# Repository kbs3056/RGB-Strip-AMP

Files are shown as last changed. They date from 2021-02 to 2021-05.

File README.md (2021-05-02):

# RGB-Strip-AMP

12V RGB LED strip amplifier is used to reduce the voltage drop in long LED strips.

### Output
3x1.5A, 2.5-5m 5050 LED.

Amplifier needs an external 12V and GND supply lines.
All LED strips connected in one circuit should be powered by the same power supply. (Input 12V and Output 12V rails are connected.)

See wiring diagram. https://github.com/kbs3056/RGB-Strip-AMP/blob/main/wiring_diagram.pdf

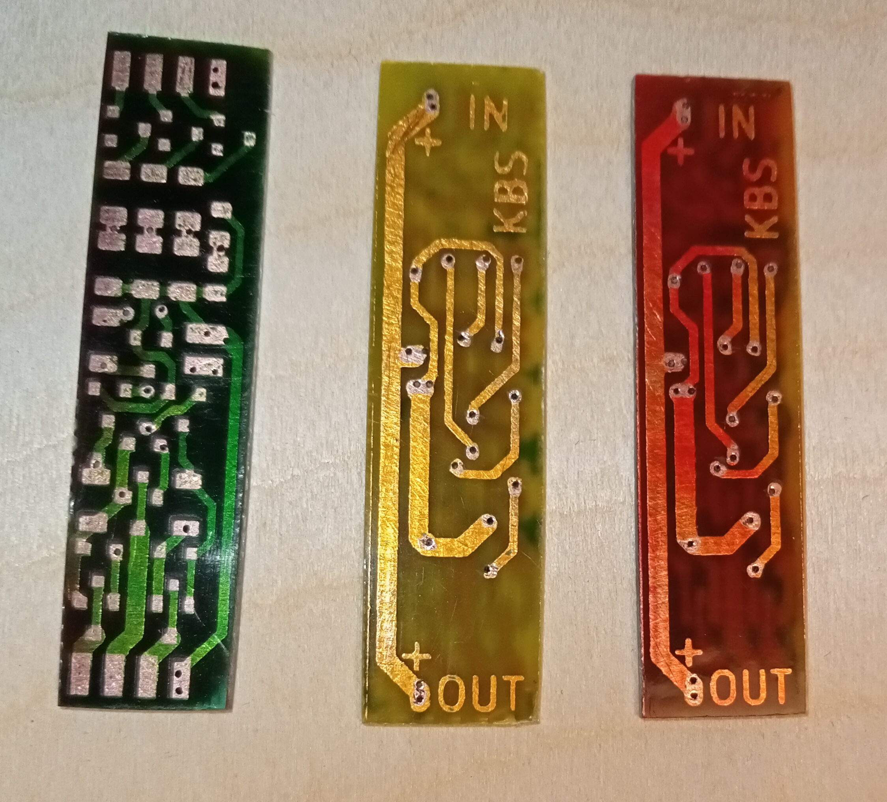
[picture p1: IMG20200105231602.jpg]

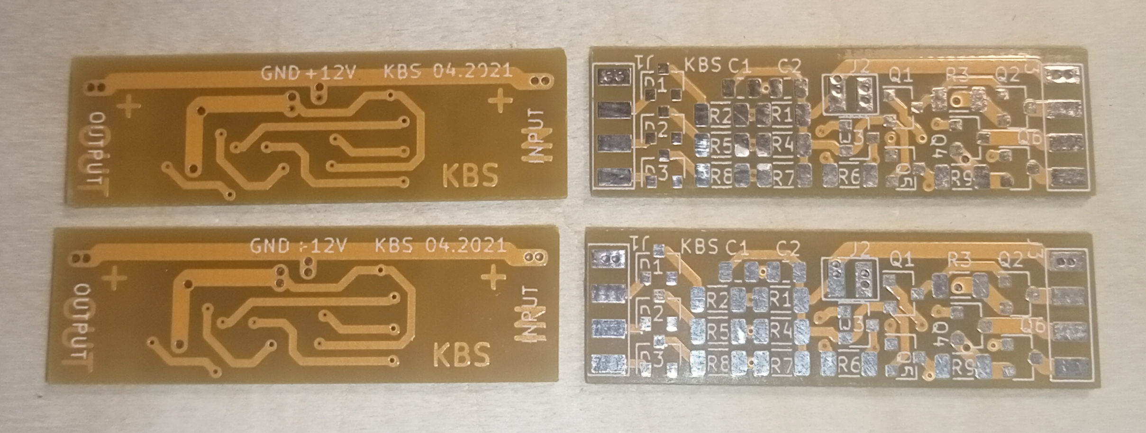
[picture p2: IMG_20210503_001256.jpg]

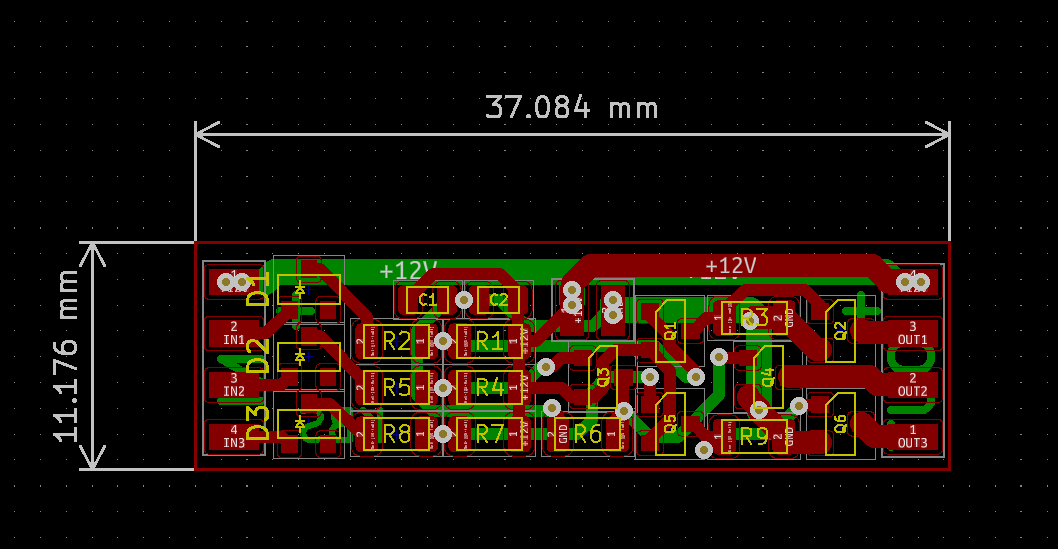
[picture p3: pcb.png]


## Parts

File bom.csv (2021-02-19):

Reference | Quantity | Value | Footprint | Datasheet
C1 | 1 | 1u | Capacitor_SMD:C_0805_2012Metric | ~
C2 | 1 | 100n | Capacitor_SMD:C_0805_2012Metric | ~
D1 D2 D3 | 3 | 3V9 | Diode_SMD:D_SOT-23_ANK | ~
Q1 Q3 Q5 | 3 | MMBT3906 | Package_TO_SOT_SMD:SOT-23 | https://www.onsemi.com/pub/Collateral/2N3906-D.PDF
Q2 Q4 Q6 | 3 | AO3400A | Package_TO_SOT_SMD:SOT-23 | http://www.aosmd.com/pdfs/datasheet/AO3400A.pdf
R1 R2 R3 R4 R5 R6 R7 R8 R9 | 9 | 4k7 | Resistor_SMD:R_1206_3216Metric | ~

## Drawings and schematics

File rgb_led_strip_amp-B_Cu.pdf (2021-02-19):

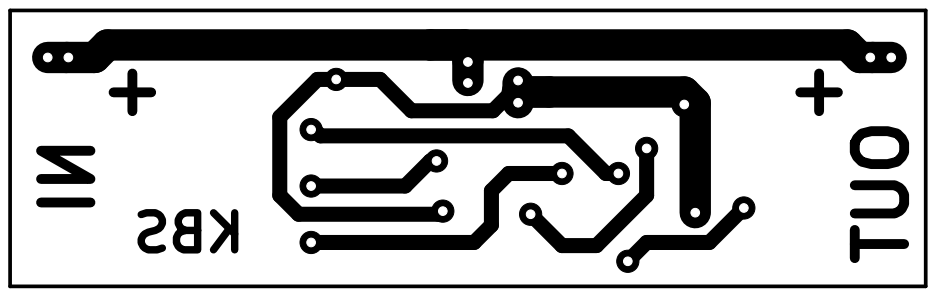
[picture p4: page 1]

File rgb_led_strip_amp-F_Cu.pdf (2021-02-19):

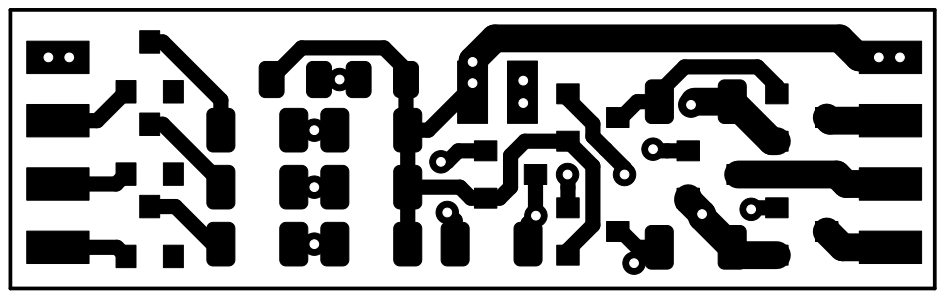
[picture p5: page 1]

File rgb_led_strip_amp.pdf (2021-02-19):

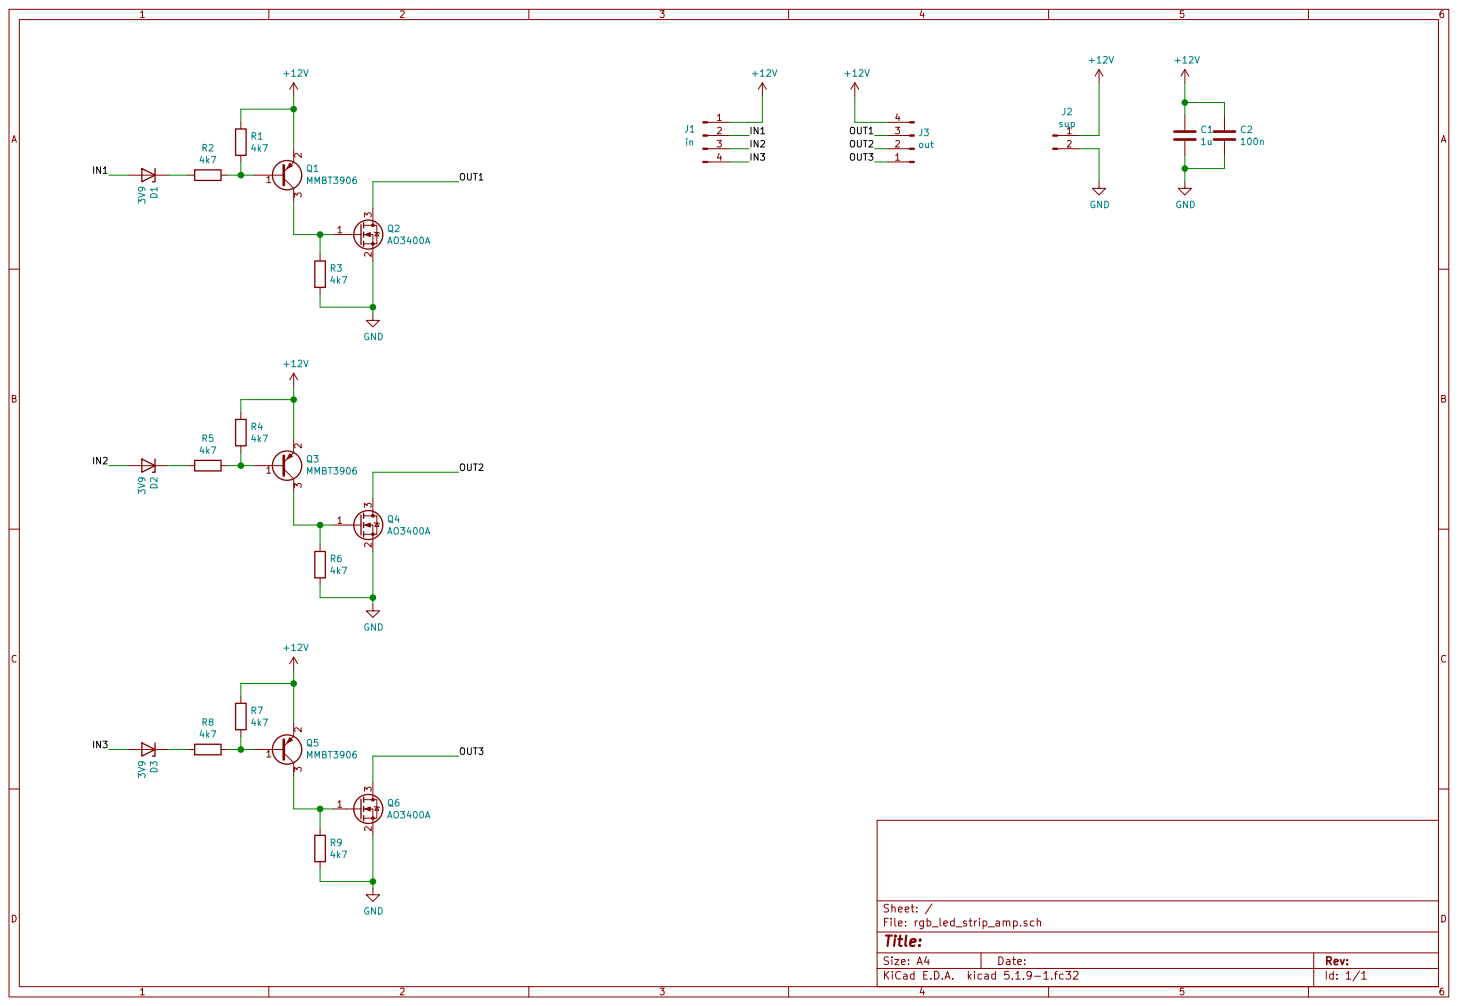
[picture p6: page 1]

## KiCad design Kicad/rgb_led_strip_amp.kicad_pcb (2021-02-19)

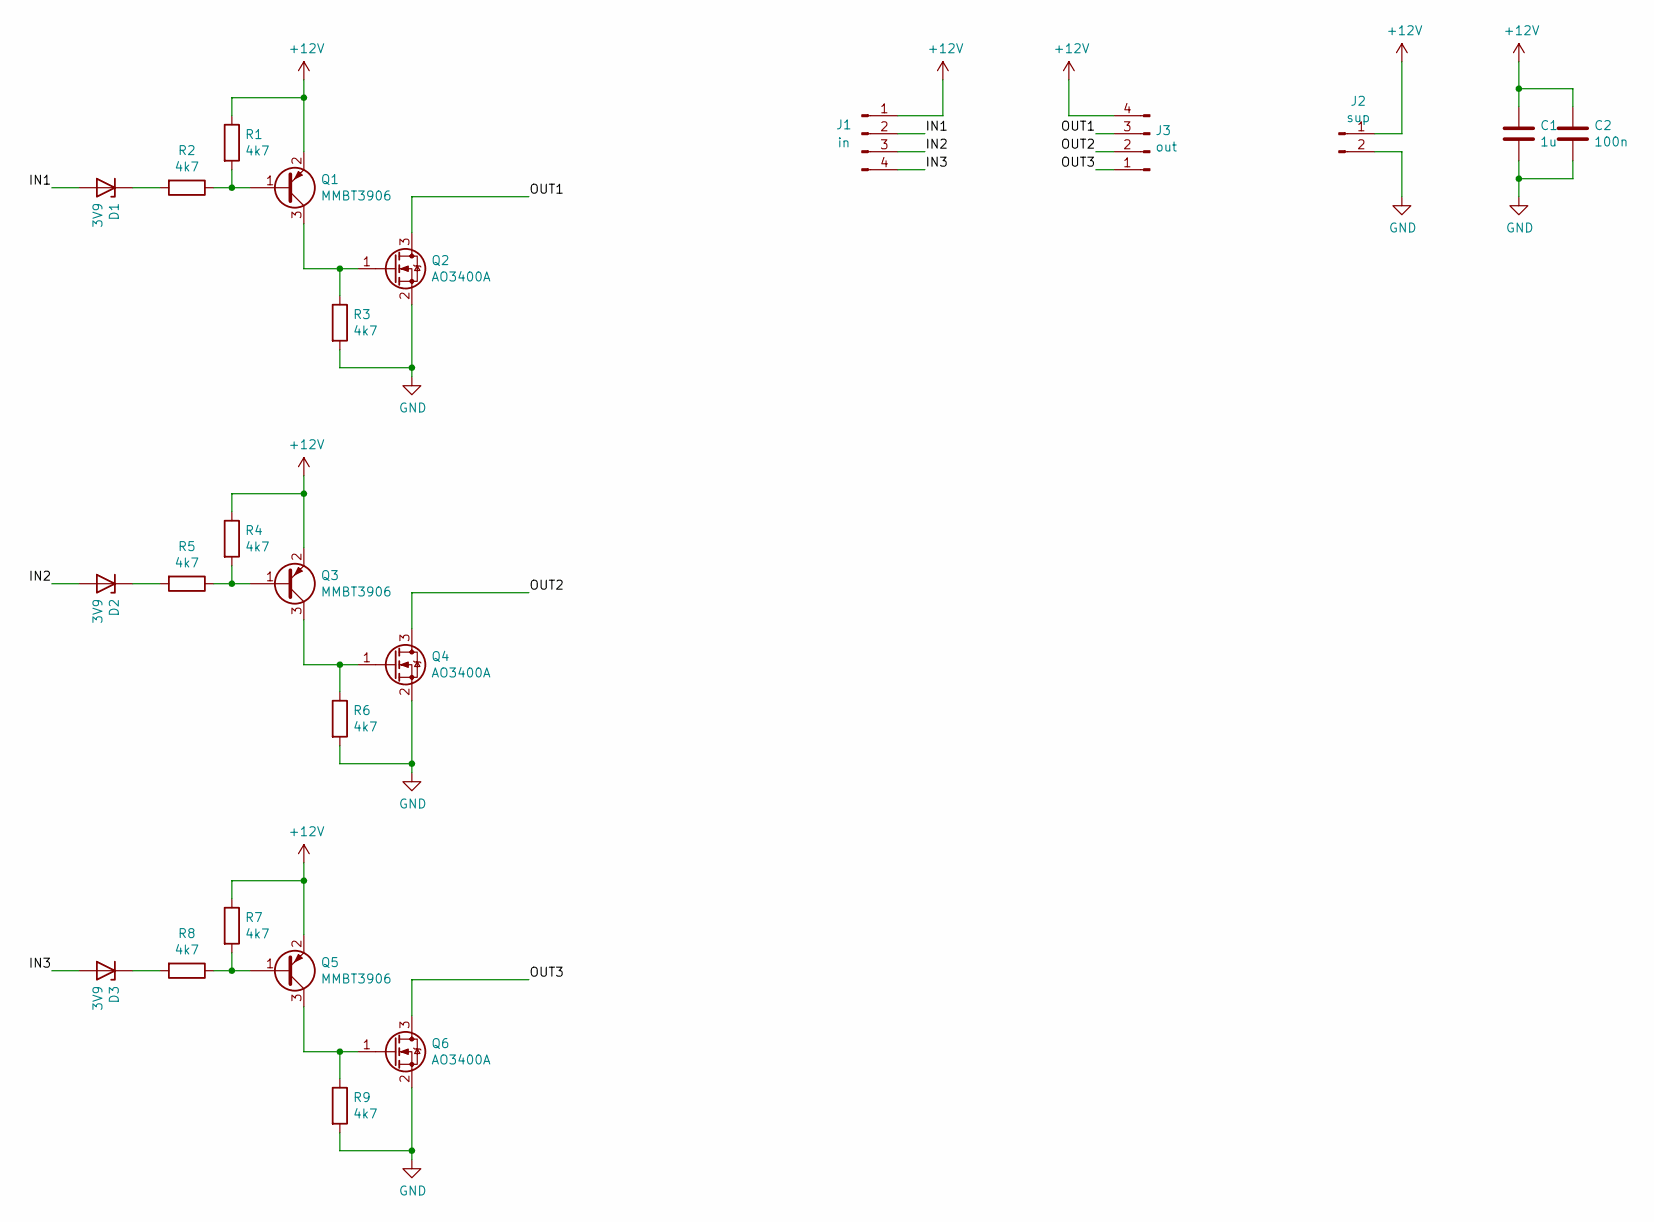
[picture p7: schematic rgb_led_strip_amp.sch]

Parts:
C1: 1u; C_0805_2012Metric
C2: 100n; C_0805_2012Metric
D1, D2, D3: 3V9; D_SOT-23_ANK
J1: in; solderpad_4_copy
J2: sup; solderpad_2
J3: out; solderpad_4_copy
Q1, Q3, Q5: MMBT3906; SOT-23
Q2, Q4, Q6: AO3400A; SOT-23
R1, R2, R3, R4, R5, R6, R7, R8, R9: 4k7; R_1206_3216Metric

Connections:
+12V: C1.1, C2.1, J1.1, J2.1, J3.4, Q1.2 (E), Q3.2 (E), Q5.2 (E), R1.1, R4.1, R7.1
/IN1: D1.2 (A), J1.2
/IN2: D2.2 (A), J1.3
/IN3: D3.2 (A), J1.4
/OUT1: J3.3, Q2.3 (D)
/OUT2: J3.2, Q4.3 (D)
/OUT3: J3.1, Q6.3 (D)
GND: C1.2, C2.2, J2.2, Q2.2 (S), Q4.2 (S), Q6.2 (S), R3.2, R6.2, R9.2
unnamed: D1.1 (K), R2.2
unnamed: D2.1 (K), R5.2
unnamed: D3.1 (K), R8.2
unnamed: Q1.1 (B), R1.2, R2.1
unnamed: Q1.3 (C), Q2.1 (G), R3.1
unnamed: Q3.1 (B), R4.2, R5.1
unnamed: Q3.3 (C), Q4.1 (G), R6.1
unnamed: Q5.1 (B), R7.2, R8.1
unnamed: Q5.3 (C), Q6.1 (G), R9.1

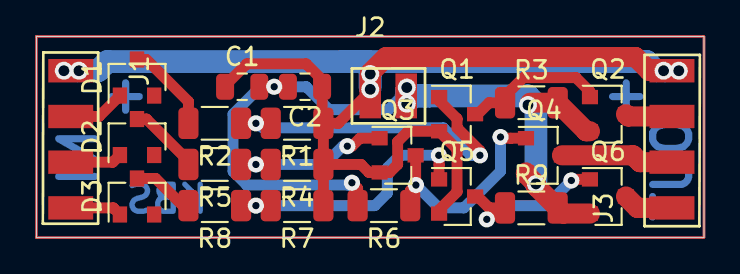
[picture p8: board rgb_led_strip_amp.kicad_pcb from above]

Board: 2 copper layers, 37.1 x 11.2 mm, 23 parts (0 on the bottom side), 17 nets.

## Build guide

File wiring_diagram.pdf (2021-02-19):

PS1

RGB
DRIVER | LED STRIP | RGB
AMP | LED STRIP

PS1

RGB
DRIVER | LED STRIP | RGB
AMP | LED STRIP

OR
